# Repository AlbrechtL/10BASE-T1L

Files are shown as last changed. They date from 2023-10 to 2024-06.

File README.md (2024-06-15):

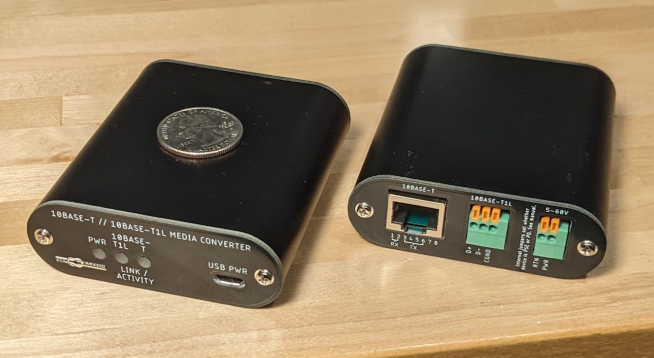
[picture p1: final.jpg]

<p class="center"><i>Completed 10BASE-T1L Adapters</i></p>

The final design and production files for the main PCB are in the 'rev3' folder. 

The end plates are in the 'panels' folder.

If you want to build this yourself, you need to buy three parts in addition to having the main PCB assembled by JLCPCB and having JLCPCB fab the end plates:

<ul>
  <li>1x <a href="https://www.digikey.com/en/products/detail/dialight/5151069F/1769784?s=N4IgTCBcDaIKwEZEAYBsBOAYiAugXyA">5151069F light pipe</a></li>
  <li>1x <a href="https://a.co/d/4ymOL0K">Aluminum Enclosure</a></li>
  <li>4x m2.5 pan head screws (the enclosure scomes with flat countersunk head screws which I don't care for)</li>
</ul>

Additional information on this project can be found <a href="http://robruark.com/projects/10BASE-T1L/10BASE-T1L.html">here</a>.

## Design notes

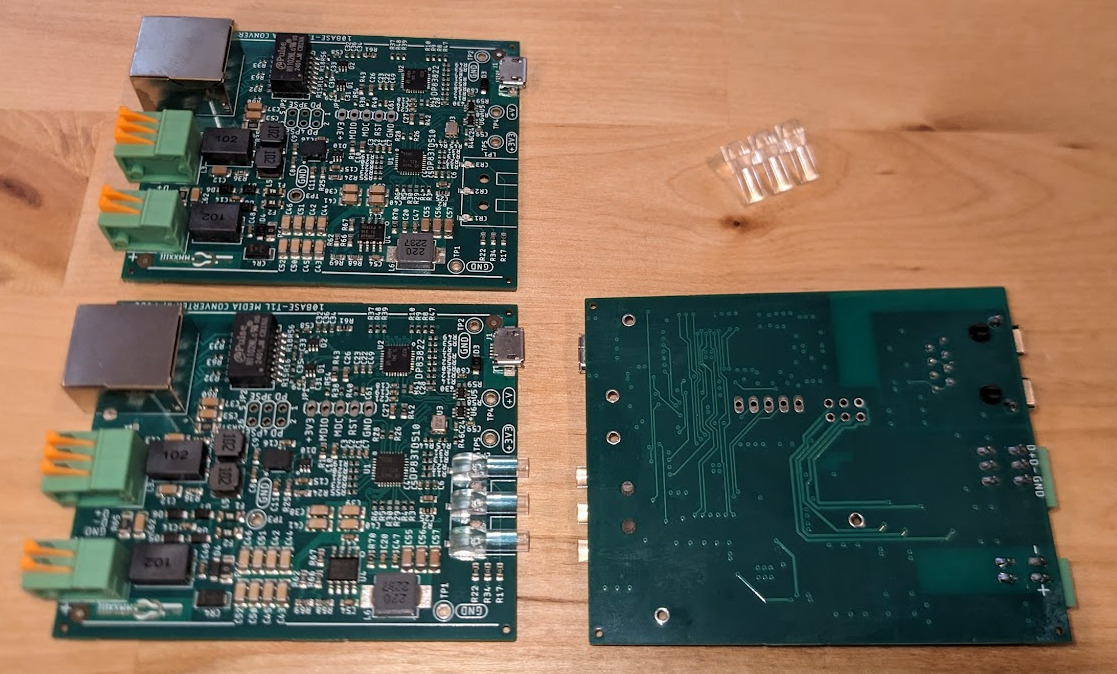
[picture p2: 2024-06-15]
finalbare.jpg

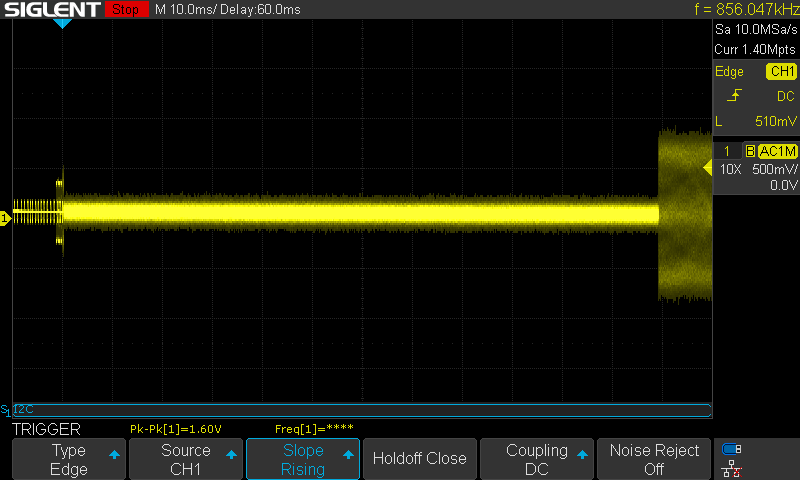
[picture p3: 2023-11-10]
png/SDS00063.png

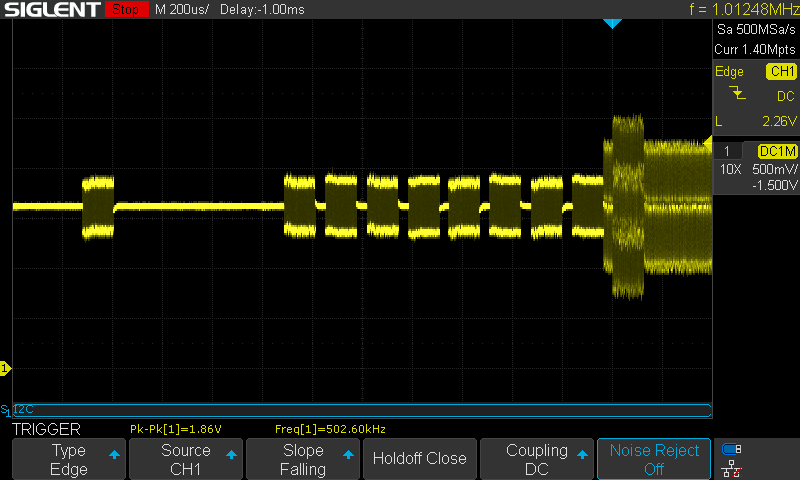
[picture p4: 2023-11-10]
png/SDS00045.png

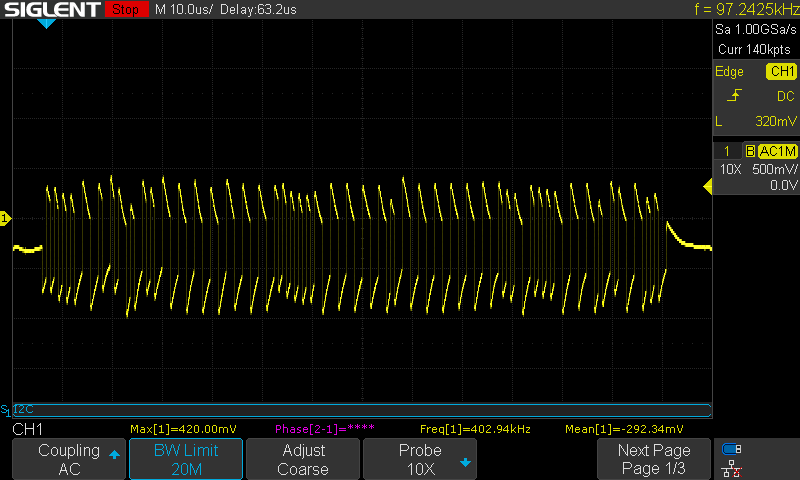
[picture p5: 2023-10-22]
png/SDS00019.png

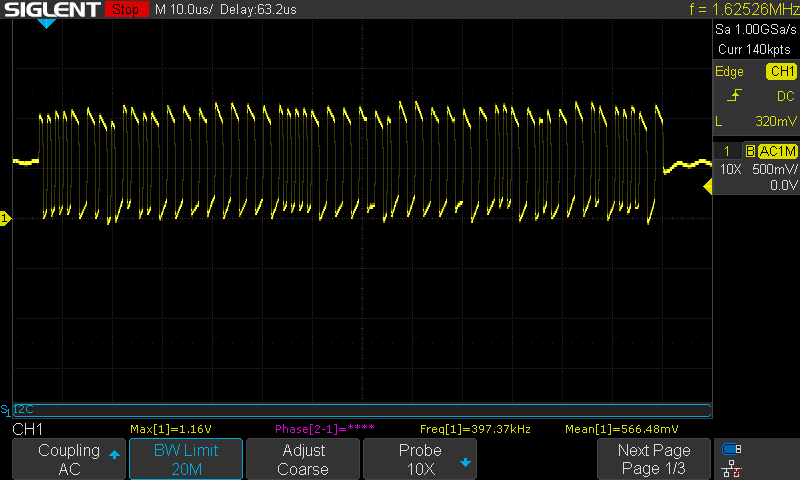
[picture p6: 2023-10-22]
png/SDS00021.png

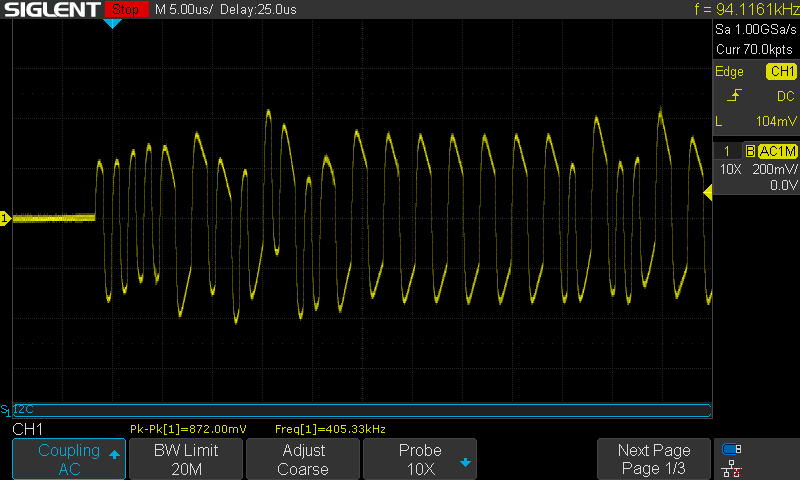
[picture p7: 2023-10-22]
png/SDS00032.png

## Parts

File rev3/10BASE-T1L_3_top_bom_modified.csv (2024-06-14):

Comment | Designator | Footprint | LCSC Part #
0 | R1 R2 R42 R43 R61 R70 | 603
0.1uF | C2 C5 | 0402_INDUCTOR
0.1uF | C14 C17 | 603
0.1uF | C24 C29 C33 C35 | 0402_INDUCTOR
0.1uF | C48 | 603
0.1uF | C58 C59 C60 | 0402_INDUCTOR
0.47uF | C8 C9 C16 | 603
0R | R64 | 1206
1.5k | R52 | R0402
1M | R57 R65 | 1206
1k | R13 R14 | R0402
1k | R35 R36 | 603
1mH | L2 | SNR5040 | C2827402
1mH | L3 L4 | SMCM090605 | C1692756
1mH | L5 | SNR5040 | C2827402
1nF | C19 C22 | 0402_INDUCTOR
1nF 1kV | C12 C13 C37 C53 C62 | C1206
1uF | C3 C6 | 0402_INDUCTOR
1uF | C11 | 603
1uF | C31 C32 C34 C36 | 0402_INDUCTOR
1uF | C38 C39 C40 C41 C42 C43 C44 C45 C46 C50 C51 C52 | C1206
2.2k | R31 R38 R39 R40 R54 | R0402
2.49k | R26 R27 R28 R47 R48 R49 R55 | R0402
2k | R20 R21 R50 | R0402
4.87k | R37 | R0402
5.1k | R51 | R0402
10 | R3 R4 R5 R6 R7 R8 R9 R10 R11 R12 R44 R45 R46 | R0402
10k | R53 | R0402
10nF | C1 C4 C7 C21 C23 C61 | 0402_INDUCTOR
10uF | C10 C15 C25 C26 C27 | 603
51k | R68 | 603
22uF | C55 C56 C57 | C1206
22uH | L6 | TMPC0603H | C357197
47pF | C28 C30 | 0402_INDUCTOR
49.9 | R15 R16 R18 R19 R23 | R0402
49.9 | R24 R25 | 603
49.9 | R32 R33 R56 R60 R63 | R0402
22k | R69 | 603
68k | R67 | 603
100k | R62 | 603
100nF | C20 C47 C54 | 603
100pF | C18 C49 | 0402_INDUCTOR
220k | R66 | 603
470 | R17 R22 R34 | 603
1206_FUSE | F1 F2 | 1206 | C207239
10104110-0001LF | J1 | MICRO_USB | C2931352
824501401 | CR4 | DO-214AC | C148235
ALT4532M-201-T001 | T1 | TDK_ALT | C2845101
CO32H4-25.000-33GDTST | U3 | 3.2X2.5_4SMD | C5185361
DNP | R29 R30 R41 R58 R59 | R0402
DNP | R71 | 603
DP83TD510ERHBR | U1 | QFN32-55_TI | C2862898
DP83822IRHBR | U2 | QFN32-55_TI | C601649
H1102NLT | T4 | H1102NLT | C18584
LMR38020SDDAR | U4 | SOIC8_TP_TI | C3192337
GREEN | CR2 CR3 | 0603_DIODE | C965804
RED | CR1 | 0603_DIODE | C2286
SM4007PL | D3 D4 D5 D6 D7 D8 | SOD123(AK) | C64898
SN74LVC1G17DCKR | U5 U6 | SC-70 | C10425
SP3003-02JTG | D1 D2 D10 | SC-70-5 | C151302
DNP | JP1 | 5-pin
210-82-03GB01 | JP2 | 6-pin | C390684
HC-RJ45-5622-1-4 | J2 |  | C3010550
KF141R-2.54-3P | J3 |  | C475125
KF141R-2.54-2P | J4 |  | C475124

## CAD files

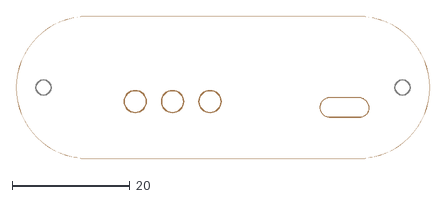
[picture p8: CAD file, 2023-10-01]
panels/10BASE-T1L_Front.dxf
70.2 x 24.2

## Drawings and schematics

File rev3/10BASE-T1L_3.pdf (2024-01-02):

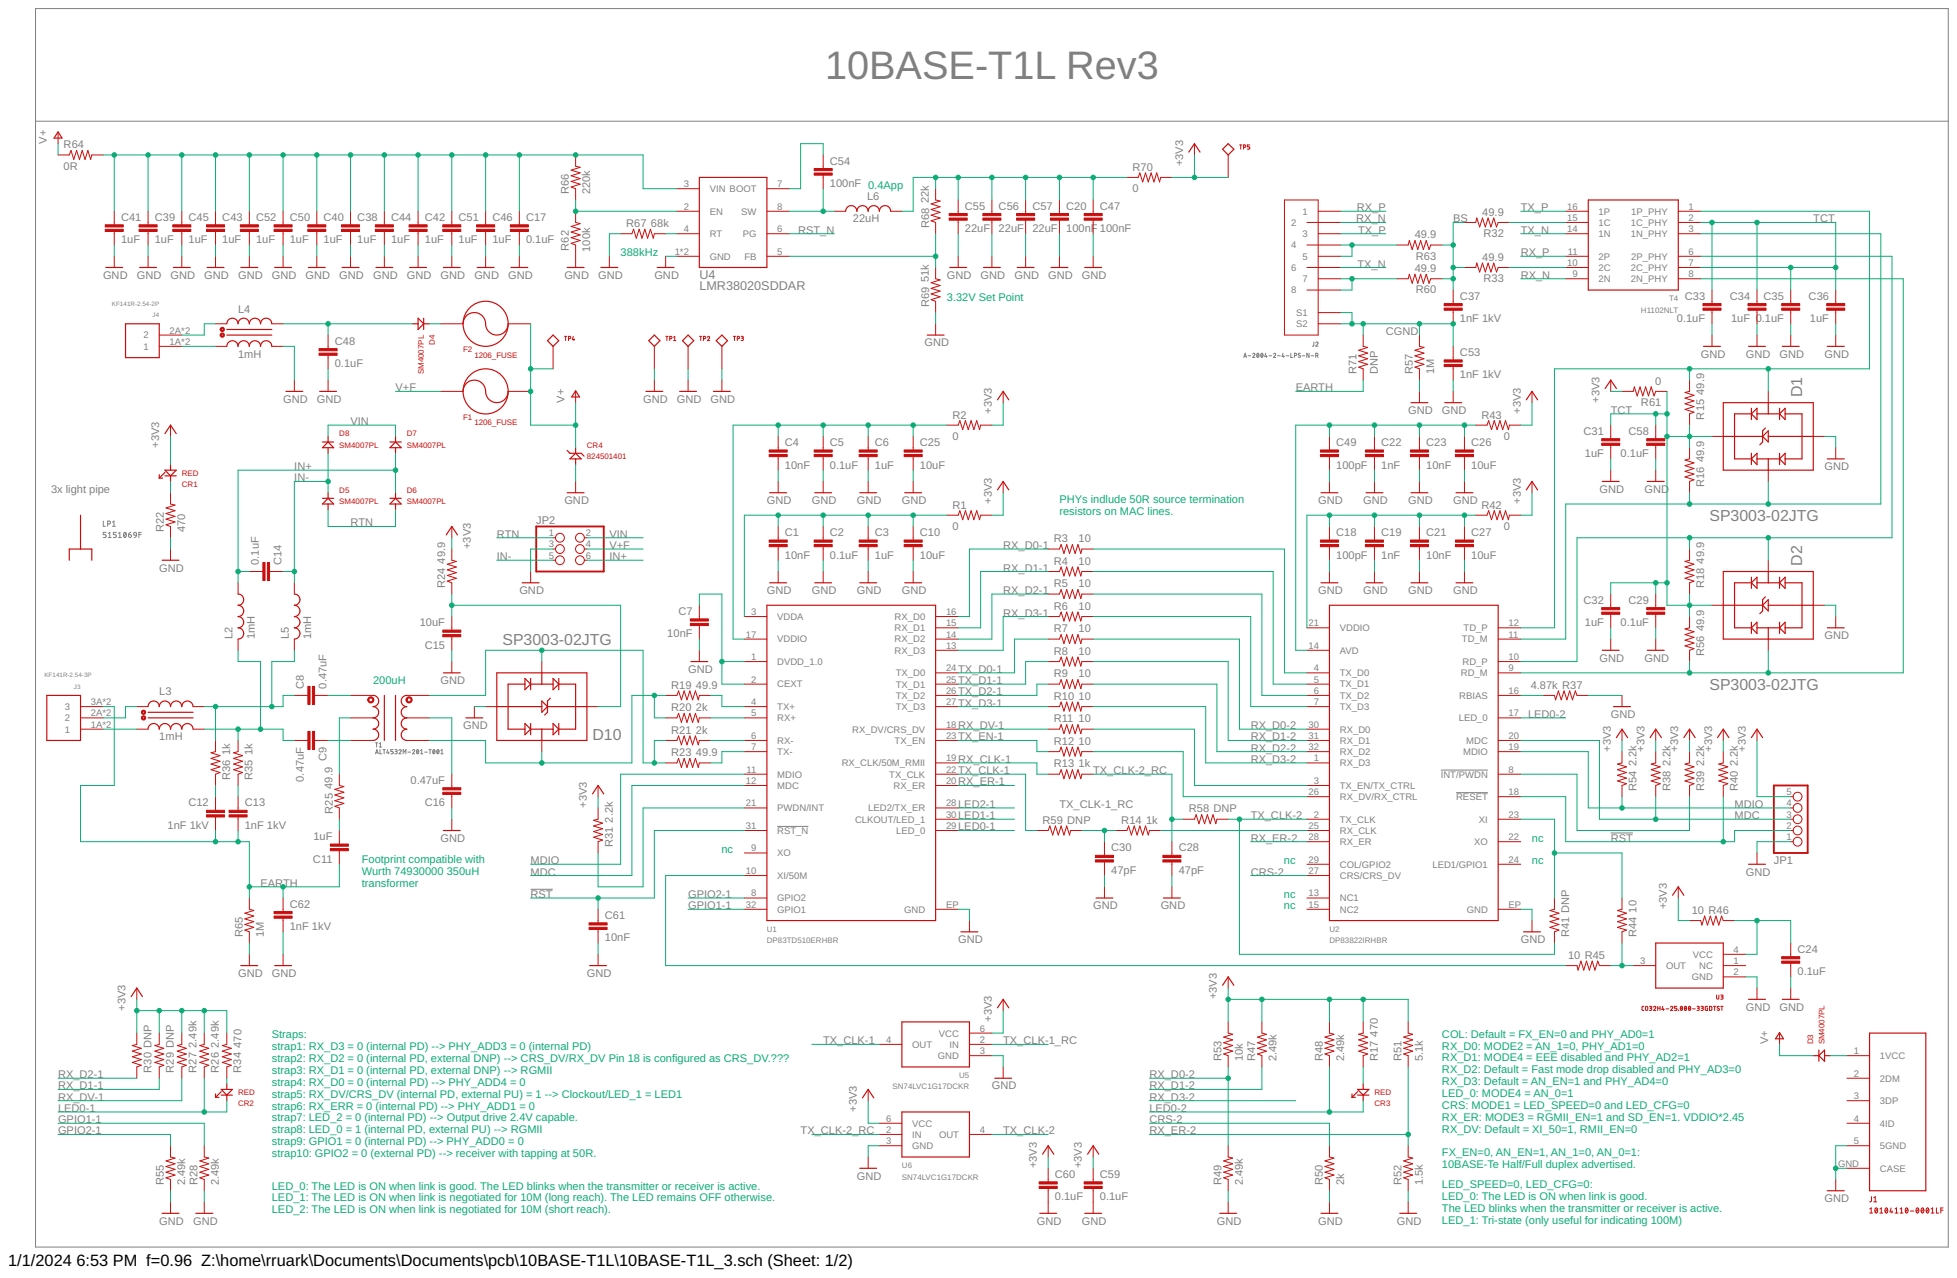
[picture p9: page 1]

PHYs indlude 50R source termination
resistors on MAC lines.

Straps: strap1: RX_D3 = 0 (internal PD) --> PHY_ADD3 = 0 (internal PD) strap2: RX_D2 = 0 (internal PD, external DNP) --> CRS_DV/RX_DV Pin 18 is configured as CRS_DV.???

COL: Default = FX_EN=0 and PHY_AD0=1
RX_D0: MODE2 = AN_1=0, PHY_AD1=0
RX_D1: MODE4 = EEE disabled and PHY_AD2=1
RX_D2: Default = Fast mode drop disabled and PHY_AD3=0
RX_D3: Default = AN_EN=1 and PHY_AD4=0
LED_0: MODE4 = AN_0=1
CRS: MODE1 = LED_SPEED=0 and LED_CFG=0
RX_ER: MODE3 = RGMII_EN=1 and SD_EN=1. VDDIO*2.45
RX_DV: Default = XI_50=1, RMII_EN=0

strap3: RX_D1 = 0 (internal PD, external DNP) --> RGMII strap4: RX_D0 = 0 (internal PD) --> PHY_ADD4 = 0

strap5: RX_DV/CRS_DV (internal PD, external PU) = 1 --> Clockout/LED_1 = LED1
strap6: RX_ERR = 0 (internal PD) --> PHY_ADD1 = 0
strap7: LED_2 = 0 (internal PD) --> Output drive 2.4V capable. strap8: LED_0 = 1 (internal PD, external PU) --> RGMII strap9: GPIO1 = 0 (internal PD) --> PHY_ADD0 = 0

strap10: GPIO2 = 0 (external PD) --> receiver with tapping at 50R. LED_0: The LED is ON when link is good. The LED blinks when the transmitter or receiver is active. LED_1: The LED is ON when link is negotiated for 10M (long reach). The LED remains OFF otherwise. LED_2: The LED is ON when link is negotiated for 10M (short reach).

FX_EN=0, AN_EN=1, AN_1=0, AN_0=1: 10BASE-Te Half/Full duplex advertised.

LED_SPEED=0, LED_CFG=0: LED_0: The LED is ON when link is good. The LED blinks when the transmitter or receiver is active. LED_1: Tri-state (only useful for indicating 100M)

1/1/2024 6:53 PM f=0.96 Z:\home\rruark\Documents\Documents\pcb\10BASE-T1L\10BASE-T1L_3.sch (Sheet: 1/2)

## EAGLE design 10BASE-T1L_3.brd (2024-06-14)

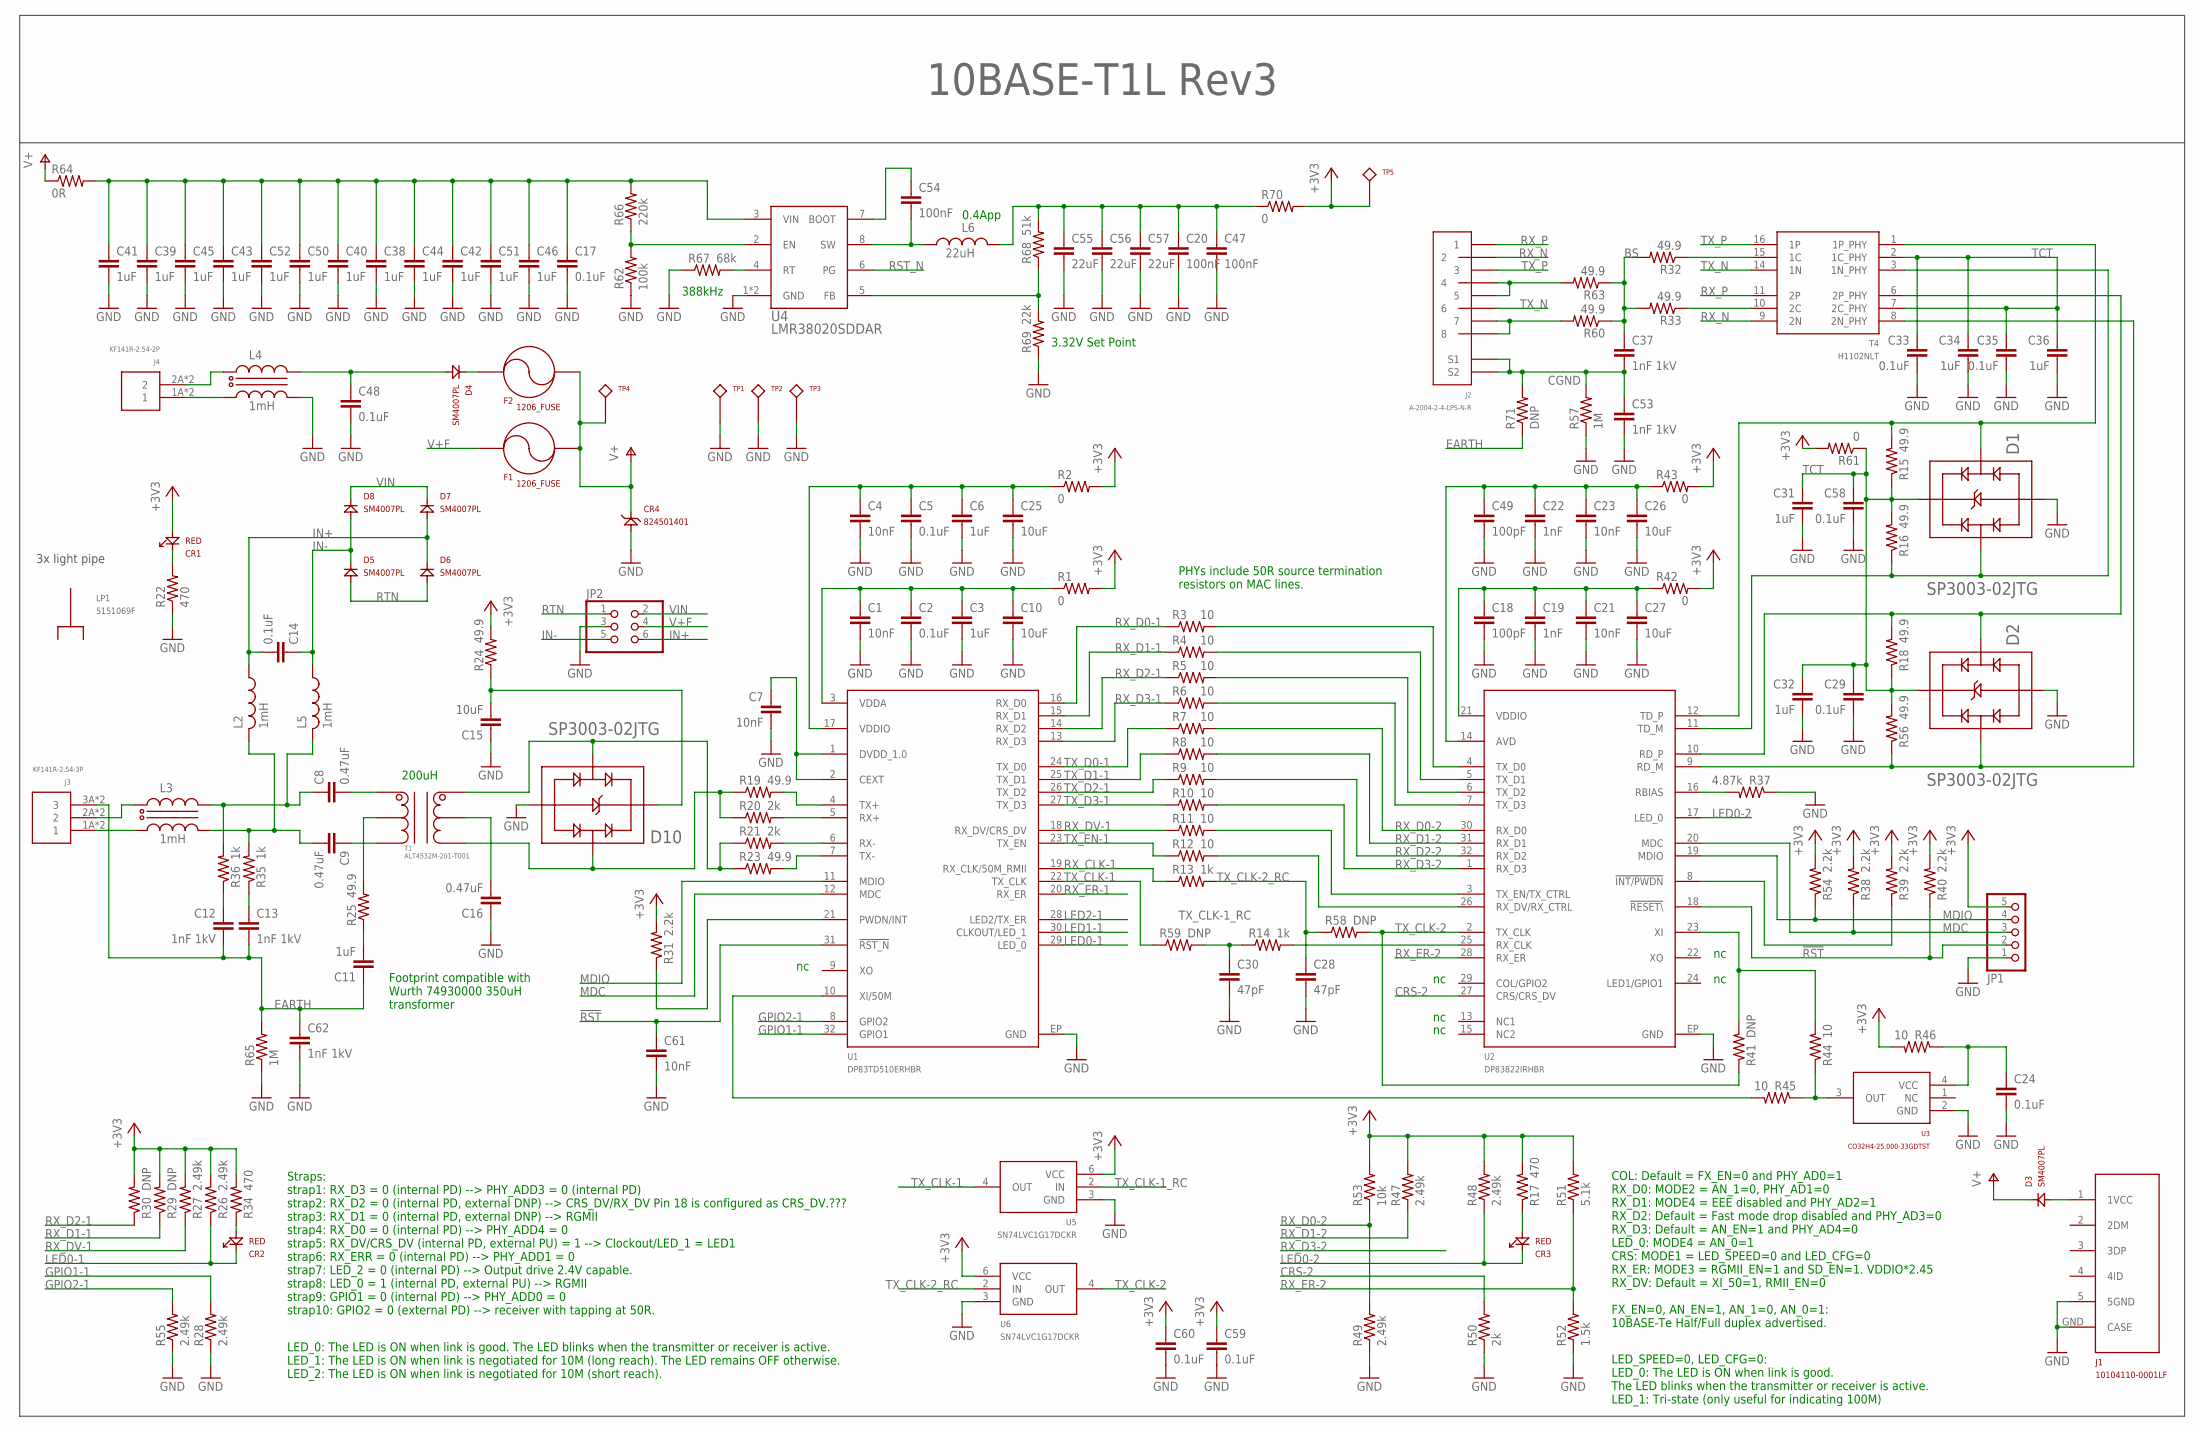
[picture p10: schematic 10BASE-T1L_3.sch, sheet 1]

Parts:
C1, C4, C7, C21, C23, C61: 10nF; 0402_INDUCTOR
C2, C5, C24, C29, C33, C35, C58, C59, C60: 0.1uF; 0402_INDUCTOR
C3, C6, C31, C32, C34, C36: 1uF; 0402_INDUCTOR
C8, C9, C16: 0.47uF; 0603
C10, C15, C25, C26, C27: 10uF; 0603
C11: 1uF; 0603
C12, C13, C37, C53, C62: 1nF 1kV; C1206
C14, C17, C48: 0.1uF; 0603
C18, C49: 100pF; 0402_INDUCTOR
C19, C22: 1nF; 0402_INDUCTOR
C20, C47, C54: 100nF; 0603
C28, C30: 47pF; 0402_INDUCTOR
C38, C39, C40, C41, C42, C43, C44, C45, C46, C50, C51, C52: 1uF; C1206
C55, C56, C57: 22uF; C1206
CR1, CR2, CR3: RED; 0603_DIODE
CR4: 824501401; DO-214AC
D1, D2, D10: SP3003-02JTG; SC-70-5
D3, D4, D5, D6, D7, D8: SM4007PL; SOD123(AK)
F1, F2: 1206_FUSE; 1206
J1: 10104110-0001LF; MICRO_USB
J2: A-2004-2-4-LPS-N-R
J3: KF141R-2.54-3P
J4: KF141R-2.54-2P
JP1: PINHD-1X5; 1X05
JP2: PINHD-2X3; 2X03
L2, L5: 1mH; SNR5040
L3, L4: 1mH; SMCM090605
L6: 22uH; TMPC0603H
LP1: 5151069F
R1, R2, R42, R43, R61, R70: 0; 0603
R3, R4, R5, R6, R7, R8, R9, R10, R11, R12, R44, R45, R46: 10; R0402
R13, R14: 1k; R0402
R15, R16, R18, R19, R23, R32, R33, R56, R60, R63: 49.9; R0402
R17, R22, R34: 470; 0603
R20, R21, R50: 2k; R0402
R24, R25: 49.9; 0603
R26, R27, R28, R47, R48, R49, R55: 2.49k; R0402
R29, R30, R41, R58, R59: DNP; R0402
R31, R38, R39, R40, R54: 2.2k; R0402
R35, R36: 1k; 0603
R37: 4.87k; R0402
R51: 5.1k; R0402
R52: 1.5k; R0402
R53: 10k; R0402
R57, R65: 1M; 1206
R62: 100k; 0603
R64: 0R; 1206
R66: 220k; 0603
R67: 68k; 0603
R68: 51k; 0603
R69: 22k; 0603
R71: DNP; 0603
T1: ALT4532M-201-T001; TDK_ALT
T4: H1102NLT
TP1, TP2, TP3: 5011; 5010
TP4, TP5: 5010
U1: DP83TD510ERHBR; QFN32-55_TI
U2: DP83822IRHBR; QFN32-55_TI
U3: CO32H4-25.000-33GDTST; 3.2X2.5_4SMD
U4: LMR38020SDDAR; SOIC8_TP_TI
U5, U6: SN74LVC1G17DCKR; SC-70

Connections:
3V3R: C20.1, C47.1, C55.1, C56.1, C57.1, L6.P$1, R68.2, R70.1
!RST: C61.P$1 (1), JP1.2, R40.1, U1.31 (!RST_N), U2.18 (!RESET\)
+3V3: C59.P$1 (1), C60.P$1 (1), CR1.A, JP1.5, R1.2, R2.2, R17.2, R24.2, R26.2, R27.2, R29.2, R30.2, R31.2, R34.2, R38.2, R39.2, R40.2, R42.2, R43.2, R46.2, R47.2, R48.2, R51.2, R53.2, R54.2, R61.2, R70.2, TP5.P$1, U5.6 (VCC), U6.6 (VCC)
BS: C37.1, R32.2, R33.2, R60.1, R63.1
CEXT_L: C7.P$1 (1), U1.1 (DVDD_1.0), U1.2 (CEXT)
CGND: C37.2, C53.1, J2.S1, J2.S2, R57.2, R71.2
CRS-2: R50.2, U2.27 (CRS/CRS_DV)
EARTH: C11.1, C12.2, C13.2, C62.1, J3.3A (3), J3.3B (3), R65.2, R71.1
GND: C1.P$2 (2), C2.P$2 (2), C3.P$2 (2), C4.P$2 (2), C5.P$2 (2), C6.P$2 (2), C7.P$2 (2), C10.2, C15.1, C16.1, C17.2, C18.P$2 (2), C19.P$2 (2), C20.2, C21.P$2 (2), C22.P$2 (2), C23.P$2 (2), C24.P$2 (2), C25.2, C26.2, C27.2, C28.P$2 (2), C29.P$2 (2), C30.P$2 (2), C31.P$2 (2), C32.P$2 (2), C33.P$2 (2), C34.P$2 (2), C35.P$2 (2), C36.P$2 (2), C38.2, C39.2, C40.2, C41.2, C42.2, C43.2, C44.2, C45.2, C46.2, C47.2, C48.2, C49.P$2 (2), C50.2, C51.2, C52.2, C53.2, C55.2, C56.2, C57.2, C58.P$2 (2), C59.P$2 (2), C60.P$2 (2), C61.P$2 (2), C62.2, CR4.A, D1.2 (GND), D2.2 (GND), D10.2 (GND), J1.5 (5GND), J1.GND (CASE), JP1.1, JP2.3, L4.OUT2 (2OUT), R22.1, R28.1, R37.1, R49.1, R50.1, R52.1, R55.1, R57.1, R62.1, R65.1, R67.1, R69.1, TP1.P$1, TP2.P$1, TP3.P$1, U1.EP (GND), U2.EP (GND), U3.2 (GND), U4.1 (GND), U4.TP (GND), U5.3 (GND), U6.3 (GND)
GPIO1-1: R28.2, U1.32 (GPIO1)
GPIO2-1: R55.2, U1.8 (GPIO2)
IN+: C14.2, D6.K, D7.A, JP2.6, L2.P$1 (1)
IN+L: C9.2, L2.P$2 (2), L3.OUT2 (2OUT), R35.2
IN-: C14.1, D5.K, D8.A, JP2.5, L5.P$1 (1)
IN-L: C8.1, L3.OUT1 (1OUT), L5.P$2 (2), R36.2
LED0-1: CR2.K, R26.1, U1.29 (LED_0)
LED0-2: CR3.K, R48.1, U2.17 (LED_0)
LED1-1: U1.30 (CLKOUT/LED_1)
LED2-1: U1.28 (LED2/TX_ER)
MDC: JP1.3, R38.1, U1.12 (MDC), U2.20 (MDC)
MDIO: JP1.4, R54.1, U1.11 (MDIO), U2.19 (MDIO)
unnamed: C48.1, D4.A, L4.OUT1 (1OUT)
unnamed: C8.2, T1.1
unnamed: CR3.A, R17.1
unnamed: J2.4, J2.5, R63.2
unnamed: J2.7, J2.8, R60.2
unnamed: CR2.A, R34.1
unnamed: R31.1, U1.21 (PWDN/INT)
unnamed: D3.A, J1.1 (1VCC)
unnamed: J4.1A (1), J4.1B (1), L4.IN2 (2IN)
unnamed: R14.2, U2.25 (RX_CLK)
unnamed: C9.1, T1.2 (3)
unnamed: R25.2, T1.6 (2)
unnamed: CR1.K, R22.2
unnamed: D4.K, F2.1
unnamed: R12.2, U2.26 (RX_DV/RX_CTRL)
unnamed: R11.2, U2.3 (TX_EN/TX_CTRL)
unnamed: R62.2, R66.1, U4.2 (EN)
unnamed: R32.1, T4.15 (1C)
unnamed: R6.2, U2.7 (TX_D3)
unnamed: R5.2, U2.6 (TX_D2)
unnamed: R4.2, U2.5 (TX_D1)
unnamed: R3.2, U2.4 (TX_D0)
unnamed: J4.2A (2), J4.2B (2), L4.IN1 (1IN)
unnamed: J3.1A (1), J3.1B (1), L3.IN2 (2IN)
unnamed: C11.2, R25.1
unnamed: R41.2, R44.2, U2.23 (XI)
unnamed: C16.2, T1.3 (5)
unnamed: C12.1, R36.1
unnamed: C13.1, R35.1
unnamed: J3.2A (2), J3.2B (2), L3.IN1 (1IN)
unnamed: C15.2, D10.3 (VCC), R24.1
unnamed: R39.1, U2.8 (!INT/PWDN)
unnamed: R68.1, R69.2, U4.5 (FB)
unnamed: R37.2, U2.16 (RBIAS)
unnamed: R44.1, R45.1, U3.3 (OUT)
unnamed: C24.P$1 (1), R46.1, U3.4 (VCC)
unnamed: R45.2, U1.10 (XI/50M)
unnamed: R33.1, T4.10 (2C)
unnamed: C54.1, U4.7 (BOOT)
unnamed: R67.2, U4.4 (RT)
RD_N: D2.5 (IO1), R56.1, T4.8 (2N_PHY), U2.9 (RD_M)
RD_P: D2.4 (IO2), R18.2, T4.6 (2P_PHY), U2.10 (RD_P)
RST_N: U4.6 (PG)
RTN: D5.A, D6.A, JP2.1
RXR_N: R21.2, U1.6 (RX-)
RXR_P: R20.2, U1.5 (RX+)
RX_CLK-1: R13.1, U1.19 (RX_CLK/50M_RMII)
RX_D0-1: R3.1, U1.16 (RX_D0)
RX_D0-2: R7.2, R49.2, R53.1, U2.30 (RX_D0)
RX_D1-1: R4.1, R29.1, U1.15 (RX_D1)
RX_D1-2: R8.2, R47.1, U2.31 (RX_D1)
RX_D2-1: R5.1, R30.1, U1.14 (RX_D2)
RX_D2-2: R9.2, U2.32 (RX_D2)
RX_D3-1: R6.1, U1.13 (RX_D3)
RX_D3-2: R10.2, U2.1 (RX_D3)
RX_DV-1: R11.1, R27.1, U1.18 (RX_DV/CRS_DV)
RX_ER-1: U1.20 (RX_ER)
RX_ER-2: R51.1, R52.2, U2.28 (RX_ER)
RX_N: J2.2, T4.9 (2N)
RX_P: J2.1, T4.11 (2P)
SW: C54.2, L6.P$2, U4.8 (SW)
T1L_N: D10.5 (IO1), R21.1, R23.1, T1.5 (6)
T1L_P: D10.4 (IO2), R19.1, R20.1, T1.4
TCT: C29.P$1 (1), C31.P$1 (1), C32.P$1 (1), C33.P$1 (1), C34.P$1 (1), C35.P$1 (1), C36.P$1 (1), C58.P$1 (1), D1.3 (VCC), D2.3 (VCC), R15.1, R16.2, R18.1, R56.2, R61.1, T4.2 (1C_PHY), T4.7 (2C_PHY)
TD_N: D1.5 (IO1), R16.1, T4.3 (1N_PHY), U2.11 (TD_M)
TD_P: D1.4 (IO2), R15.2, T4.1 (1P_PHY), U2.12 (TD_P)
TXR_N: R23.2, U1.7 (TX-)
TXR_P: R19.2, U1.4 (TX+)
TX_CLK-1: R59.1, U1.22 (TX_CLK), U5.4 (OUT)
TX_CLK-1_RC: C30.P$1 (1), R14.1, R59.2, U5.2 (IN)
TX_CLK-2: R41.1, R58.2, U2.2 (TX_CLK), U6.4 (OUT)
TX_CLK-2_RC: C28.P$1 (1), R13.2, R58.1, U6.2 (IN)
TX_D0-1: R7.1, U1.24 (TX_D0)
TX_D1-1: R8.1, U1.25 (TX_D1)
TX_D2-1: R9.1, U1.26 (TX_D2)
TX_D3-1: R10.1, U1.27 (TX_D3)
TX_EN-1: R12.1, U1.23 (TX_EN)
TX_N: J2.6, T4.14 (1N)
TX_P: J2.3, T4.16 (1P)
V+: CR4.C (K), D3.K, F1.2, F2.2, R64.1, TP4.P$1
V+F: F1.1, JP2.4
V+R: C17.1, C38.1, C39.1, C40.1, C41.1, C42.1, C43.1, C44.1, C45.1, C46.1, C50.1, C51.1, C52.1, R64.2, R66.2, U4.3 (VIN)
VDDA_L: C1.P$1 (1), C2.P$1 (1), C3.P$1 (1), C10.1, R1.1, U1.3 (VDDA)
VDDA_L1: C18.P$1 (1), C19.P$1 (1), C21.P$1 (1), C27.1, R42.1, U2.21 (VDDIO)
VDDIO_L: C4.P$1 (1), C5.P$1 (1), C6.P$1 (1), C25.1, R2.1, U1.17 (VDDIO)
VDDIO_L1: C22.P$1 (1), C23.P$1 (1), C26.1, C49.P$1 (1), R43.1, U2.14 (AVD)
VIN: D7.K, D8.K, JP2.2

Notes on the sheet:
Straps: strap1: RX_D3 = 0 (internal PD) --> PHY_ADD3 = 0 (internal PD) strap2: RX_D2 = 0 (internal PD, external DNP) --> CRS_DV/RX_DV Pin 18 is configured as CRS_DV.??? strap3: RX_D1 = 0 (internal PD, external DNP) --> RGMII strap4: RX_D0 = 0 (internal PD) --> PHY_ADD4 = 0 strap5: RX_DV/CRS_DV (int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
LED_0: The LED is ON when link is good. The LED blinks when the transmitter or receiver is active. LED_1: The LED is ON when link is negotiated for 10M (long reach). The LED remains OFF otherwise. LED_2: The LED is ON when link is negotiated for 10M (short reach).
LED_SPEED=0, LED_CFG=0: LED_0: The LED is ON when link is good. The LED blinks when the transmitter or receiver is active. LED_1: Tri-state (only useful for indicating 100M)
COL: Default = FX_EN=0 and PHY_AD0=1 RX_D0: MODE2 = AN_1=0, PHY_AD1=0 RX_D1: MODE4 = EEE disabled and PHY_AD2=1 RX_D2: Default = Fast mode drop disabled and PHY_AD3=0 RX_D3: Default = AN_EN=1 and PHY_AD4=0 LED_0: MODE4 = AN_0=1 CRS: MODE1 = LED_SPEED=0 and LED_CFG=0 RX_ER: MODE3 = RGMII_EN=1 and SD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
3x light pipe
10BASE-T1L Rev3
388kHz
0.4App
3.32V Set Point
PHYs include 50R source termination resistors on MAC lines.
200uH
Footprint compatible with Wurth 74930000 350uH transformer

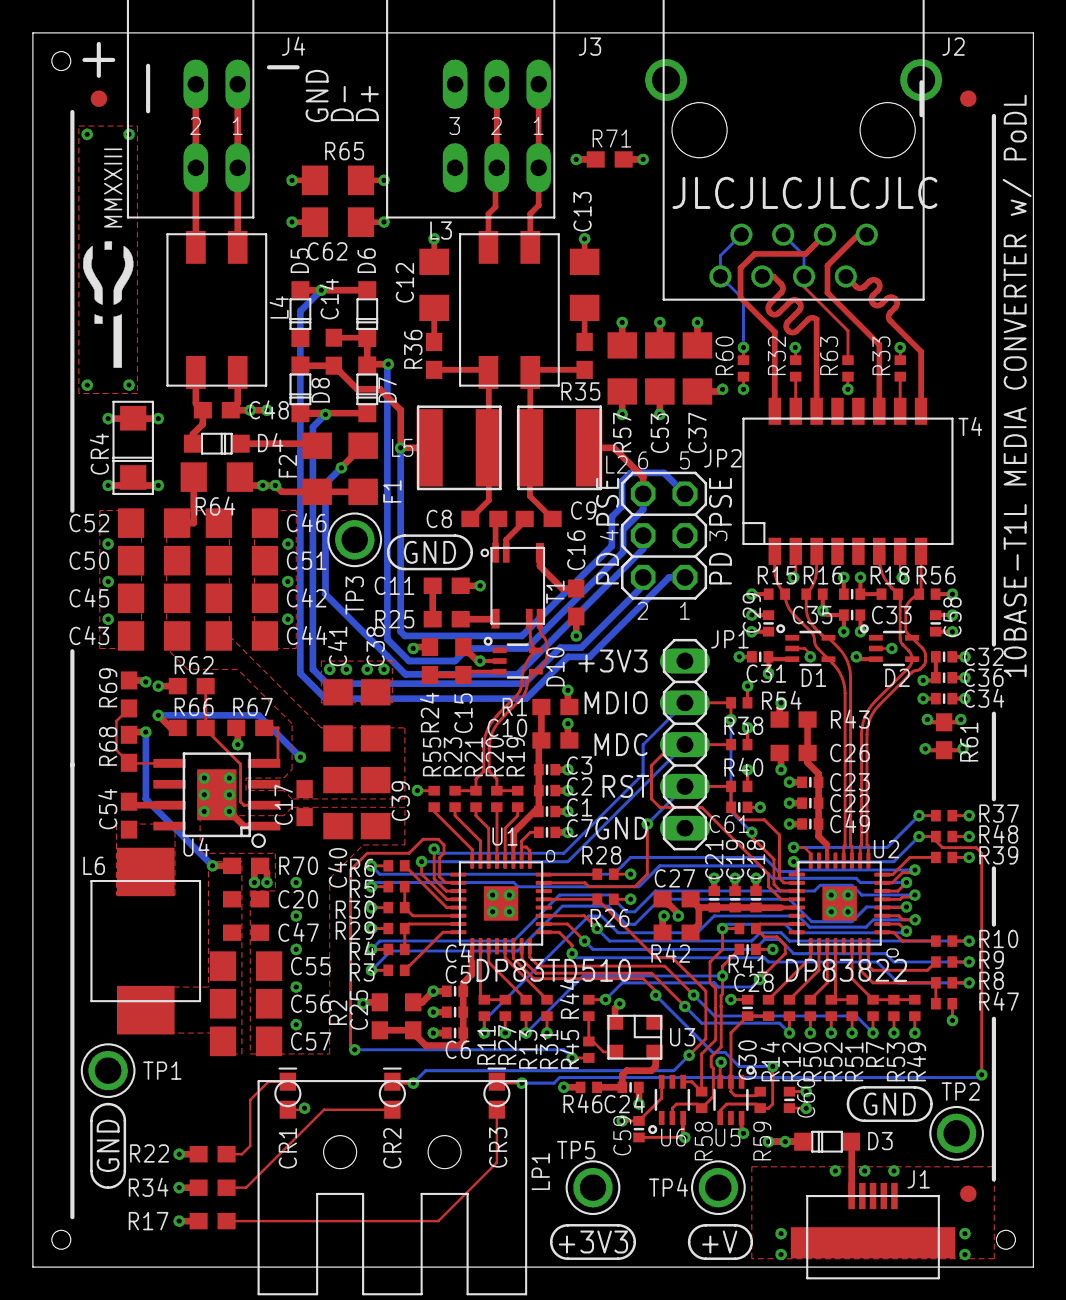
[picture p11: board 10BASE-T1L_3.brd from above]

Board: 4 copper layers, 60.8 x 75.0 mm, 173 parts (0 on the bottom side), 104 nets.

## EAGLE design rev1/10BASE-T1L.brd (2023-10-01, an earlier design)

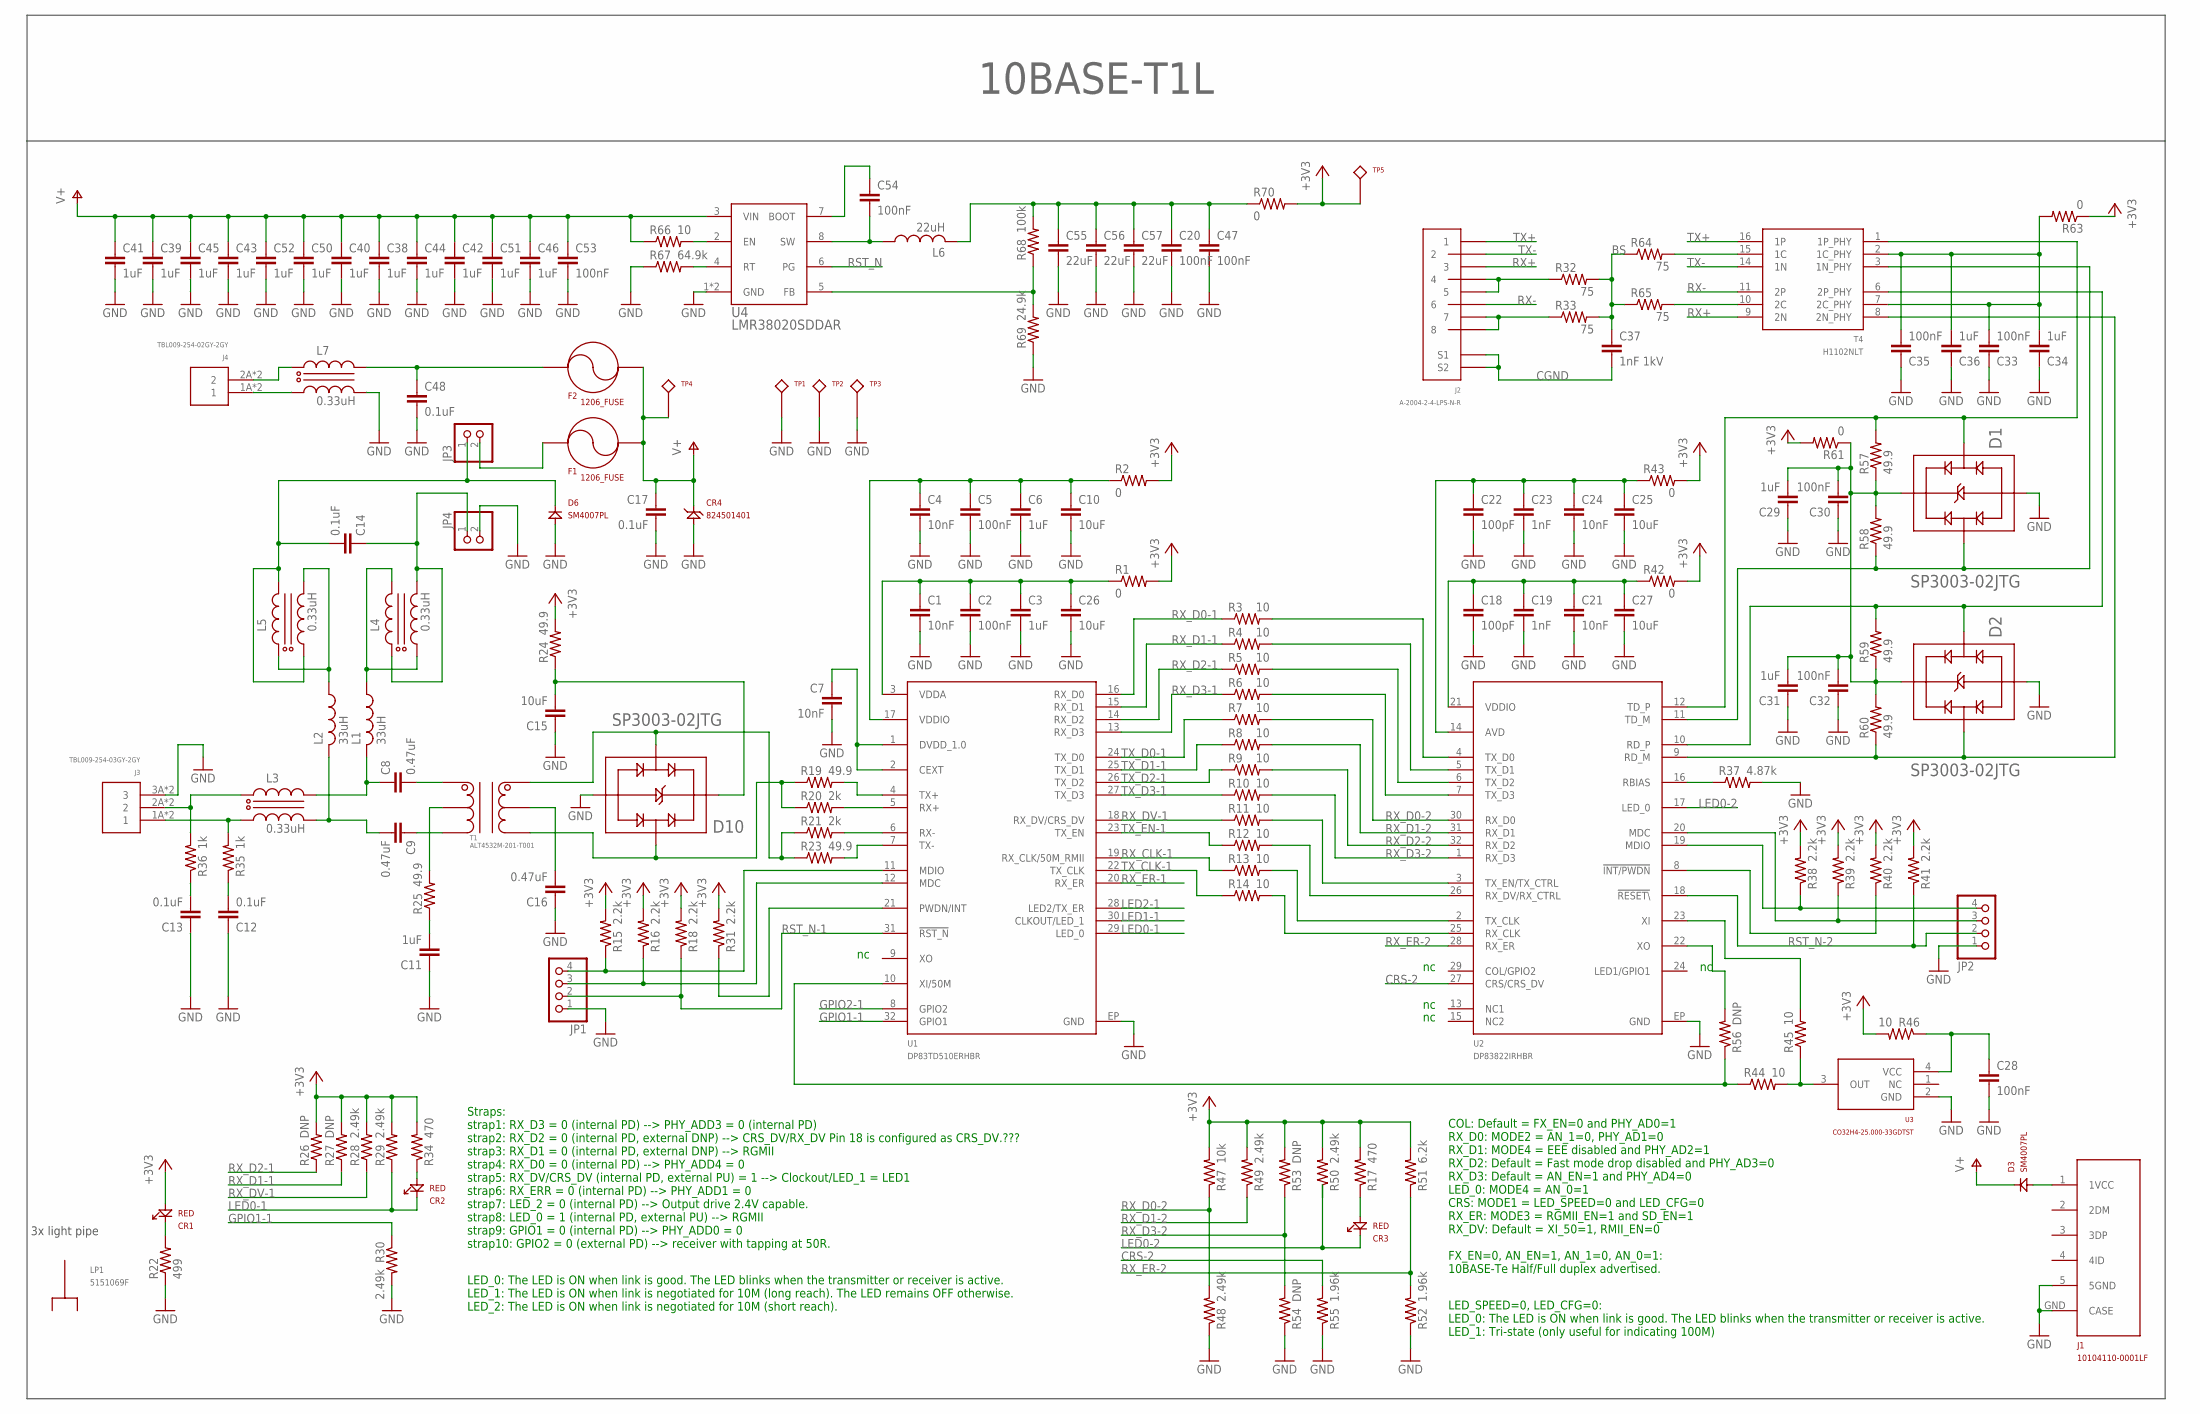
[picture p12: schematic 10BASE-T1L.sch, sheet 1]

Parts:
C1, C4, C7, C21, C24: 10nF; 0603
C2, C5, C20, C28, C30, C32, C33, C35, C47, C53, C54: 100nF; 0603
C3, C6, C11, C29, C31, C34, C36: 1uF; 0603
C8, C9, C16: 0.47uF; 0603
C10, C25, C26, C27: 10uF; 0805
C12, C13, C14, C17, C48: 0.1uF; 0603
C15: 10uF; 0603
C18, C22: 100pF; 0603
C19, C23: 1nF; 0603
C37: 1nF 1kV; C1206
C38, C39, C40, C41, C42, C43, C44, C45, C46, C50, C51, C52: 1uF; C1206
C55, C56, C57: 22uF; C1206
CR1, CR2, CR3: RED; 0603_DIODE
CR4: 824501401; DO-214AC
D1, D2, D10: SP3003-02JTG; SC-70-5
D3, D6: SM4007PL; SOD123(AK)
F1, F2: 1206_FUSE; 1206
J1: 10104110-0001LF; MICRO_USB
J2: A-2004-2-4-LPS-N-R
J3: TBL009-254-03GY-2GY
J4: TBL009-254-02GY-2GY
JP1, JP2: PINHD-1X4; 1X04
JP3, JP4: PINHD-1X2; 1X02
L1, L2: 33uH; 0806
L3, L4, L5, L7: 0.33uH; SDCW2520
L6: 22uH; APW12A10
LP1: 5151069F
R1, R2, R42, R43, R61, R63, R70: 0; 0603
R3, R4, R5, R6, R7, R8, R9, R10, R11, R12, R13, R14, R44, R45, R46, R66: 10; 0603
R15, R16, R18, R31, R38, R39, R40, R41: 2.2k; 0603
R17, R34: 470; 0603
R19, R23, R24, R25, R57, R58, R59, R60: 49.9; 0603
R20, R21: 2k; 0603
R22: 499; 0603
R26, R27, R53, R54, R56: DNP; 0603
R28, R29, R30, R48, R49, R50: 2.49k; 0603
R32, R33, R64, R65: 75; 0603
R35, R36: 1k; 0603
R37: 4.87k; 0603
R47: 10k; 0603
R51: 6.2k; 0603
R52, R55: 1.96k; 0603
R67: 64.9k; 0603
R68: 100k; 0603
R69: 24.9k; 0603
T1: ALT4532M-201-T001; TDK_ALT
T4: H1102NLT
TP1, TP2, TP3: 5011; 5010
TP4, TP5: 5010
U1: DP83TD510ERHBR; QFN32-55_TI
U2: DP83822IRHBR; QFN32-55_TI
U3: CO32H4-25.000-33GDTST; 3.2X2.5_4SMD
U4: LMR38020SDDAR; SOIC8_TP_TI

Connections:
3V3R: C20.1, C47.1, C55.1, C56.1, C57.1, L6.P$2 (2), R68.2, R70.1
+3V3: CR1.A, R1.2, R2.2, R15.2, R16.2, R17.2, R18.2, R24.2, R26.2, R27.2, R28.2, R29.2, R31.2, R34.2, R38.2, R39.2, R40.2, R41.2, R42.2, R43.2, R46.2, R47.2, R49.2, R50.2, R51.2, R53.2, R61.2, R63.1, R70.2, TP5.P$1
BS: C37.1, R32.2, R33.2, R64.1, R65.1
CEXT_L: C7.1, U1.1 (DVDD_1.0), U1.2 (CEXT)
CGND: C37.2, J2.S1, J2.S2
CRS-2: R55.2, U2.27 (CRS/CRS_DV)
GND: C1.2, C2.2, C3.2, C4.2, C5.2, C6.2, C7.2, C10.2, C11.1, C12.1, C13.1, C15.1, C16.1, C17.2, C18.2, C19.2, C20.2, C21.2, C22.2, C23.2, C24.2, C25.2, C26.2, C27.2, C28.2, C29.1, C30.1, C31.1, C32.1, C33.1, C34.1, C35.1, C36.1, C38.2, C39.2, C40.2, C41.2, C42.2, C43.2, C44.2, C45.2, C46.2, C47.2, C48.2, C50.2, C51.2, C52.2, C53.2, C55.2, C56.2, C57.2, CR4.A, D1.2 (GND), D2.2 (GND), D6.A, D10.2 (GND), J1.5 (5GND), J1.GND (CASE), J3.3A (3), J3.3B (3), JP1.1, JP2.1, JP4.2, L7.B2 (2OUT), R22.1, R30.2, R37.2, R48.1, R52.1, R54.1, R55.1, R67.1, R69.1, TP1.P$1, TP2.P$1, TP3.P$1, U1.EP (GND), U2.EP (GND), U3.2 (GND), U4.1 (GND), U4.TP (GND)
GPIO1-1: R30.1, U1.32 (GPIO1)
GPIO2-1: U1.8 (GPIO2)
LED0-1: CR2.K, R29.1, U1.29 (LED_0)
LED0-2: CR3.K, R50.1, U2.17 (LED_0)
LED1-1: U1.30 (CLKOUT/LED_1)
LED2-1: U1.28 (LED2/TX_ER)
unnamed: C48.1, F2.1, L7.A2 (1OUT)
unnamed: C8.2, T1.1
unnamed: CR3.A, R17.1
unnamed: J2.4, J2.5, R32.1
unnamed: J2.7, J2.8, R33.1
unnamed: CR2.A, R34.1
unnamed: JP1.4, R15.1, U1.11 (MDIO)
unnamed: JP1.3, R16.1, U1.12 (MDC)
unnamed: R31.1, U1.21 (PWDN/INT)
unnamed: D3.A, J1.1 (1VCC)
unnamed: R56.2, U2.22 (XO)
unnamed: J4.1A (1), J4.1B (1), L7.B1 (2IN)
unnamed: R14.2, U2.25 (RX_CLK)
unnamed: C9.1, T1.2 (3)
unnamed: R25.2, T1.6 (2)
unnamed: C8.1, L1.P$2 (2), L3.A2 (1OUT)
unnamed: C9.2, L2.P$2 (2), L3.B2 (2OUT)
unnamed: CR1.K, R22.2
unnamed: L1.P$1 (1), L4.A2 (1OUT), L4.B1 (2IN)
unnamed: L2.P$1 (1), L5.A1 (1IN), L5.B2 (2OUT)
unnamed: R13.2, U2.2 (TX_CLK)
unnamed: R12.2, U2.26 (RX_DV/RX_CTRL)
unnamed: R11.2, U2.3 (TX_EN/TX_CTRL)
unnamed: C14.2, D6.K, JP3.1, L5.A2 (1OUT), L5.B1 (2IN)
unnamed: C14.1, JP4.1, L4.A1 (1IN), L4.B2 (2OUT)
unnamed: R64.2, T4.15 (1C)
unnamed: R6.2, U2.7 (TX_D3)
unnamed: R5.2, U2.6 (TX_D2)
unnamed: R4.2, U2.5 (TX_D1)
unnamed: R3.2, U2.4 (TX_D0)
unnamed: J4.2A (2), J4.2B (2), L7.A1 (1IN)
unnamed: F1.1, JP3.2
unnamed: J3.1A (1), J3.1B (1), L3.B1 (2IN), R35.2
unnamed: C11.2, R25.1
unnamed: C16.2, T1.3 (5)
unnamed: R45.2, U2.23 (XI)
unnamed: C13.2, R36.1
unnamed: C12.2, R35.1
unnamed: J3.2A (2), J3.2B (2), L3.A1 (1IN), R36.2
unnamed: C15.2, D10.3 (VCC), R24.1
unnamed: JP2.3, R39.1, U2.20 (MDC)
unnamed: JP2.4, R38.1, U2.19 (MDIO)
unnamed: R40.1, U2.8 (!INT/PWDN)
unnamed: R68.1, R69.2, U4.5 (FB)
unnamed: R37.1, U2.16 (RBIAS)
unnamed: R44.2, R45.1, U3.3 (OUT)
unnamed: C28.1, R46.1, U3.4 (VCC)
unnamed: R44.1, R56.1, U1.10 (XI/50M)
unnamed: R65.2, T4.10 (2C)
unnamed: C54.1, U4.7 (BOOT)
unnamed: R67.2, U4.4 (RT)
unnamed: R66.2, U4.2 (EN)
RD_N: D2.5 (IO1), R60.1, T4.8 (2N_PHY), U2.9 (RD_M)
RD_P: D2.4 (IO2), R59.2, T4.6 (2P_PHY), U2.10 (RD_P)
RST_N: U4.6 (PG)
RST_N-1: JP1.2, R18.1, U1.31 (!RST_N)
RST_N-2: JP2.2, R41.1, U2.18 (!RESET\)
RX+: J2.3, T4.9 (2N)
RX-: J2.6, T4.11 (2P)
RXR_N: R21.2, U1.6 (RX-)
RXR_P: R20.2, U1.5 (RX+)
RX_CLK-1: R13.1, U1.19 (RX_CLK/50M_RMII)
RX_D0-1: R3.1, U1.16 (RX_D0)
RX_D0-2: R7.2, R47.1, R48.2, U2.30 (RX_D0)
RX_D1-1: R4.1, R27.1, U1.15 (RX_D1)
RX_D1-2: R8.2, R49.1, U2.31 (RX_D1)
RX_D2-1: R5.1, R26.1, U1.14 (RX_D2)
RX_D2-2: R9.2, U2.32 (RX_D2)
RX_D3-1: R6.1, U1.13 (RX_D3)
RX_D3-2: R10.2, R53.1, R54.2, U2.1 (RX_D3)
RX_DV-1: R11.1, R28.1, U1.18 (RX_DV/CRS_DV)
RX_ER-1: U1.20 (RX_ER)
RX_ER-2: R51.1, R52.2, U2.28 (RX_ER)
SW: C54.2, L6.P$1 (1), U4.8 (SW)
T1L_N: D10.5 (IO1), R21.1, R23.1, T1.5 (6)
T1L_P: D10.4 (IO2), R19.1, R20.1, T1.4
TCT: C33.2, C34.2, C35.2, C36.2, R63.2, T4.2 (1C_PHY), T4.7 (2C_PHY)
TCT2: C29.2, C30.2, C31.2, C32.2, D1.3 (VCC), D2.3 (VCC), R57.1, R58.2, R59.1, R60.2, R61.1
TD_N: D1.5 (IO1), R58.1, T4.3 (1N_PHY), U2.11 (TD_M)
TD_P: D1.4 (IO2), R57.2, T4.1 (1P_PHY), U2.12 (TD_P)
TX+: J2.1, T4.16 (1P)
TX-: J2.2, T4.14 (1N)
TXR_N: R23.2, U1.7 (TX-)
TXR_P: R19.2, U1.4 (TX+)
TX_CLK-1: R14.1, U1.22 (TX_CLK)
TX_D0-1: R7.1, U1.24 (TX_D0)
TX_D1-1: R8.1, U1.25 (TX_D1)
TX_D2-1: R9.1, U1.26 (TX_D2)
TX_D3-1: R10.1, U1.27 (TX_D3)
TX_EN-1: R12.1, U1.23 (TX_EN)
V+: C17.1, C38.1, C39.1, C40.1, C41.1, C42.1, C43.1, C44.1, C45.1, C46.1, C50.1, C51.1, C52.1, C53.1, CR4.C (K), D3.K, F1.2, F2.2, R66.1, TP4.P$1, U4.3 (VIN)
VDDA_L: C1.1, C2.1, C3.1, C26.1, R1.1, U1.3 (VDDA)
VDDA_L1: C18.1, C19.1, C21.1, C27.1, R42.1, U2.21 (VDDIO)
VDDIO_L: C4.1, C5.1, C6.1, C10.1, R2.1, U1.17 (VDDIO)
VDDIO_L1: C22.1, C23.1, C24.1, C25.1, R43.1, U2.14 (AVD)

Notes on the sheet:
Straps: strap1: RX_D3 = 0 (internal PD) --> PHY_ADD3 = 0 (internal PD) strap2: RX_D2 = 0 (internal PD, external DNP) --> CRS_DV/RX_DV Pin 18 is configured as CRS_DV.??? strap3: RX_D1 = 0 (internal PD, external DNP) --> RGMII strap4: RX_D0 = 0 (internal PD) --> PHY_ADD4 = 0 strap5: RX_DV/CRS_DV (int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
LED_0: The LED is ON when link is good. The LED blinks when the transmitter or receiver is active. LED_1: The LED is ON when link is negotiated for 10M (long reach). The LED remains OFF otherwise. LED_2: The LED is ON when link is negotiated for 10M (short reach).
LED_SPEED=0, LED_CFG=0: LED_0: The LED is ON when link is good. The LED blinks when the transmitter or receiver is active. LED_1: Tri-state (only useful for indicating 100M)
COL: Default = FX_EN=0 and PHY_AD0=1 RX_D0: MODE2 = AN_1=0, PHY_AD1=0 RX_D1: MODE4 = EEE disabled and PHY_AD2=1 RX_D2: Default = Fast mode drop disabled and PHY_AD3=0 RX_D3: Default = AN_EN=1 and PHY_AD4=0 LED_0: MODE4 = AN_0=1 CRS: MODE1 = LED_SPEED=0 and LED_CFG=0 RX_ER: MODE3 = RGMII_EN=1 and SD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
3x light pipe
10BASE-T1L

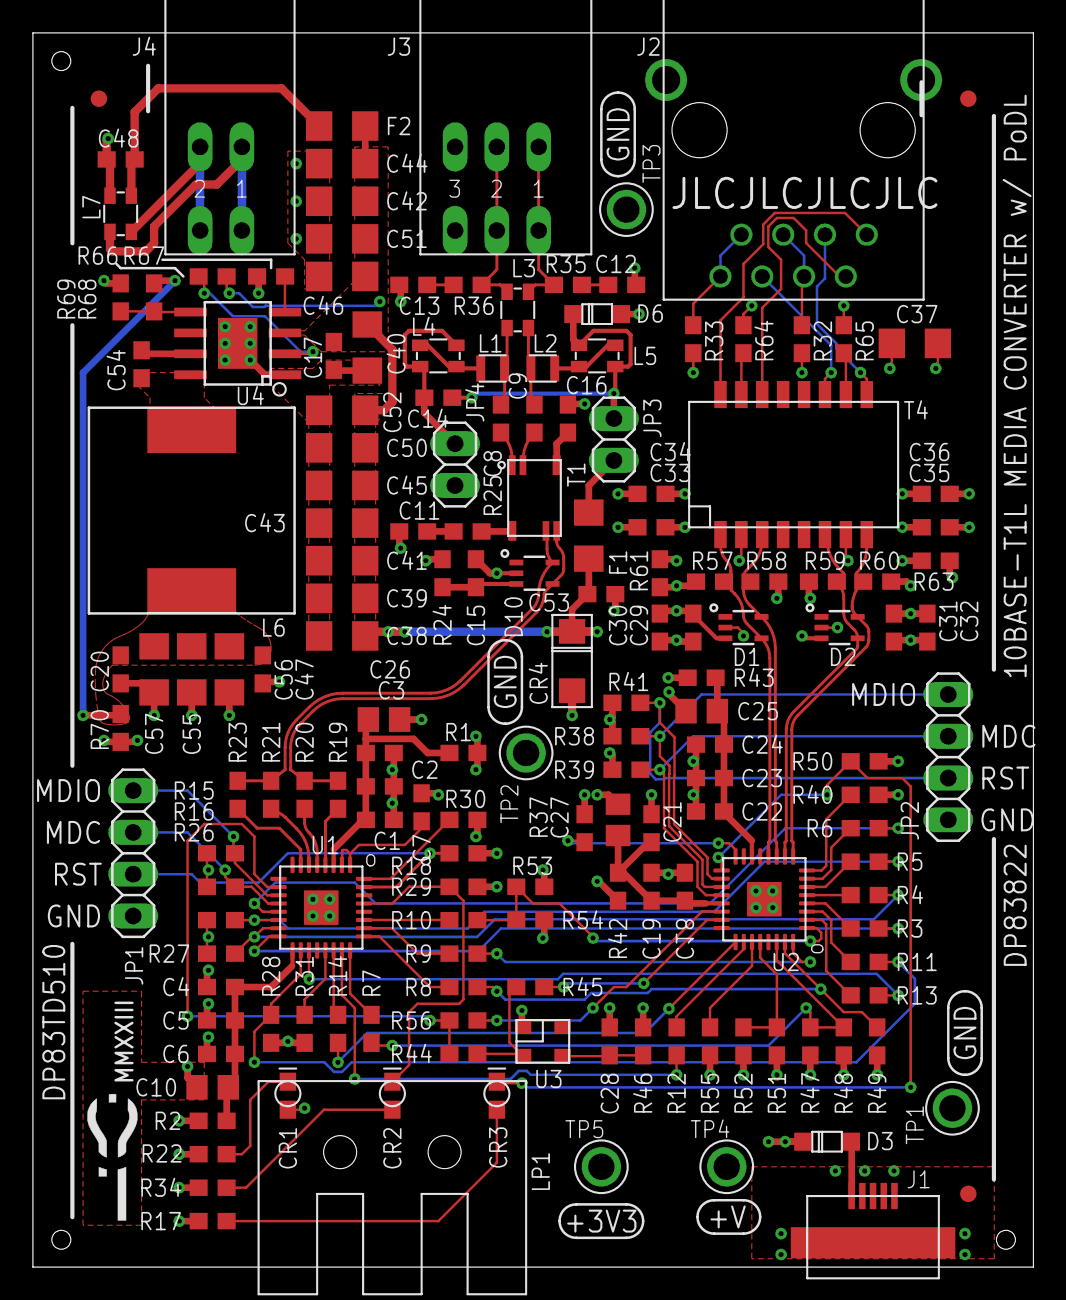
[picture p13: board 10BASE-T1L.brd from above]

Board: 4 copper layers, 60.8 x 75.0 mm, 163 parts (0 on the bottom side), 103 nets.

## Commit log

2023-10-01 adding reset cap
    [10BASE-T1L_2.brd, 10BASE-T1L_2.sch]
2023-10-02 Added PD detection
    [10BASE-T1L_2.brd, 10BASE-T1L_2.sch]
2023-10-08 Rev2
    Fixed RGMII clock
    Fixed LED package
    Fixed 3.3V PoL output voltage
    Fixed oscillator footprint
    Fixed PoDl
    Switched to JLC Available connectors
    Fixed common mode chokes.
    [10BASE-T1L_2.brd, 10BASE-T1L_2.sch, 10BASE-T1L_2_top_bom.csv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]
2023-10-10 Added front / back plates
    [10BASE-T1L_Back.brd]
2023-10-17 Loss calculations
    [10BASE-T1L_2.sch, attenuation.ods]
2023-10-22 Adding measurements
    [10BASE-T1L_3.brd, 10BASE-T1L_3.sch, attenuation.ods]
2023-11-10 updating images
    [attenuation.ods]
2024-01-02 Adding V3 with inductor PoDL
    [10BASE-T1L_3.brd, 10BASE-T1L_3.sch, 10BASE-T1L_3_top_bom.csv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]
2024-06-14 V3 Updates
    [10BASE-T1L_3.brd, 10BASE-T1L_3.sch, 10BASE-T1L_3_top_bom.csv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]
2024-06-15 Reorganized project
    [10BASE-T1L.brd, 10BASE-T1L.sch, 10BASE-T1L_2.brd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]
